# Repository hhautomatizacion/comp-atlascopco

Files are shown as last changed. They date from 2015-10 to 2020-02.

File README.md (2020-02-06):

<br/>
<p align="center">
  
</p>
<br/>

# Control de compresor Atlas Copco

## Fecha
* 2014

## Descripcion del proyecto
* Reemplazo de control electronikon

## Herramientas utilizadas
* KGL_WIN version 3.66
* DopSoft version 1.01.08

## Modelos de PLC, etc.
* PLC MasterK 120s
* HMI Delta DOP-B05S111

## Autores
* <a href="http://www.github.com/emmanuel156">emmanuel156</a> 
* <a href="http://www.github.com/pedrohermon">pedrohermon</a> 

## Comentarios
* Aparte de las funciones básicas de arrancar y parar el compresor, el programa lleva la cuenta de horas de servicio para programar los mantenimientos al compresor. También se puede programar la hora y día de la semana de arranque y paro automático del compresor así como tener un historial de eventos del mismo.

## Contenido
* Carpeta de Diagramas
	* Diagramas del proyecto
		* Diagramas electricos
		* Diagramas de bloques
		* Dibujos
* Carpeta de Documentos
	* Documentos pensados para el usuario final
		* Manuales de usuario
		* Manuales de programacion
* Carpeta de Fotos
	* Fotos del proyecto antes, durante y despues del desarrollo del mismo
		* Fotos
		* Capturas de pantalla
* Carpeta de Historial
	* Documentacion del desarrollo del proyecto
		* Hojas de datos de componentes
		* Manuales de usuario de componentes
		* Documentacion de funciones, herramientas
* Carpeta de Programas
	* Programas de Computadora, PLC, etc. 
		* Codigos fuente
		* Iconos e imagenes usados en los programas
		* Archivos de configuracion de los programas
		* Programas compilados
* Carpeta de Pruebas
	* Pruebas preliminares del proyecto
		* Programas incompletos, o secciones de programas
		* Modelos de componentes que se hayan probado

---
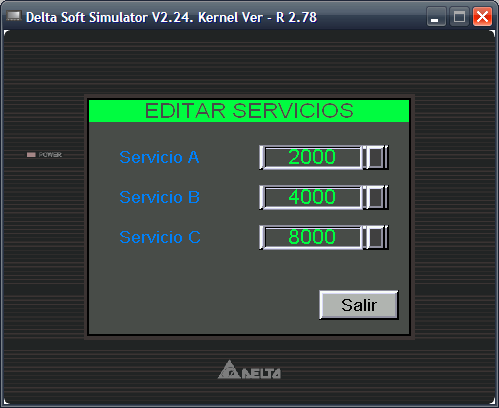
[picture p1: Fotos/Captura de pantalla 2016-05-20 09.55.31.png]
Captura de pantalla 2016-05-20 09.55.31.png

---
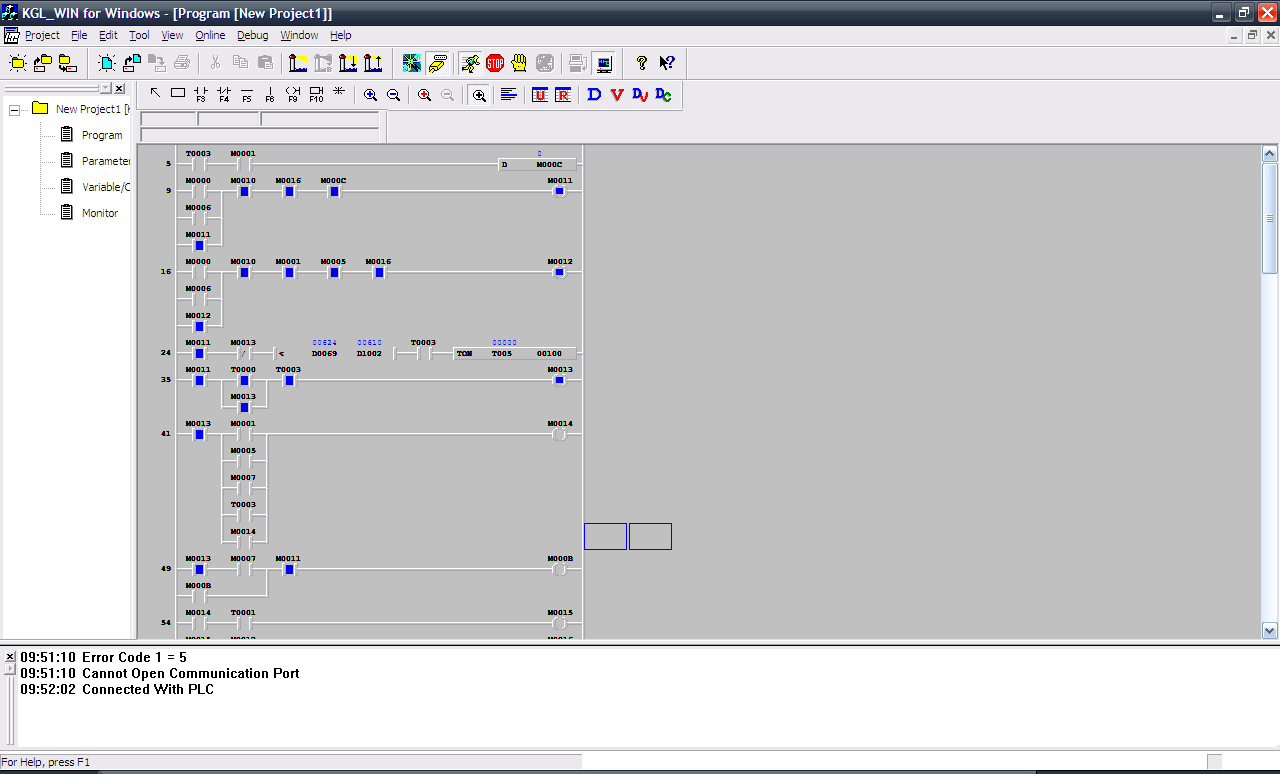
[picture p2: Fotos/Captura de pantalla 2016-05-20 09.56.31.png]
Captura de pantalla 2016-05-20 09.56.31.png

---
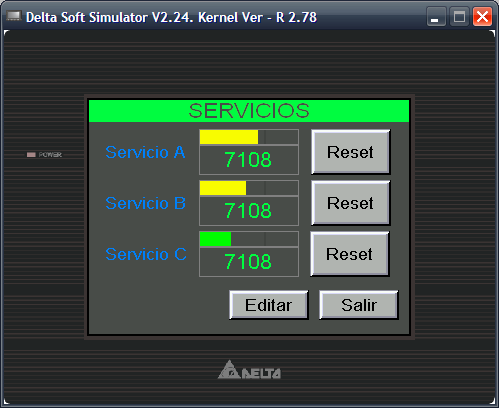
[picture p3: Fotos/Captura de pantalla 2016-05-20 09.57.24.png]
Captura de pantalla 2016-05-20 09.57.24.png

---
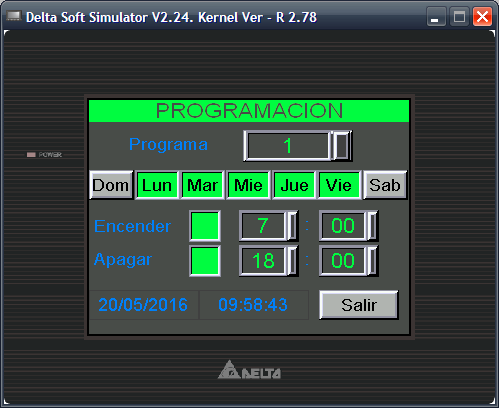
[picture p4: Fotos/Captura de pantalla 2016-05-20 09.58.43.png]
Captura de pantalla 2016-05-20 09.58.43.png

---
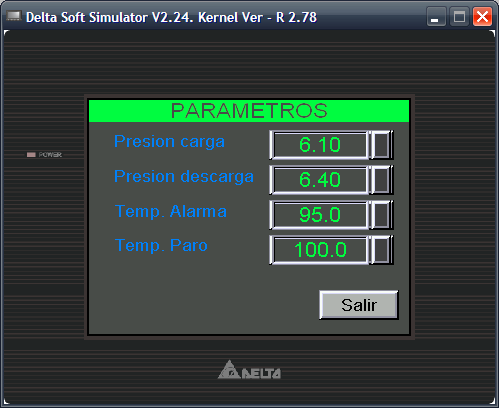
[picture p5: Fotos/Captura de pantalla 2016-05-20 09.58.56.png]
Captura de pantalla 2016-05-20 09.58.56.png

---
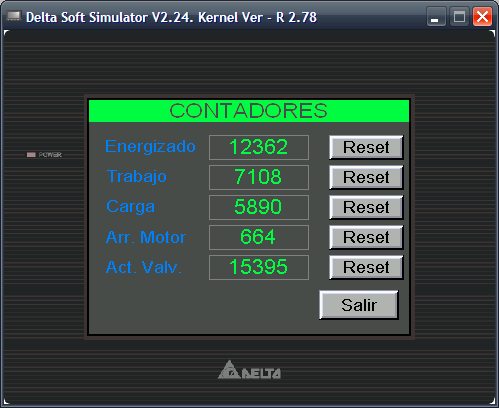
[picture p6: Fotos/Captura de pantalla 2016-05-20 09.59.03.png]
Captura de pantalla 2016-05-20 09.59.03.png

---
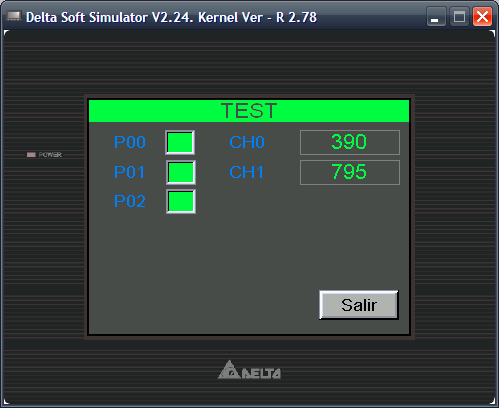
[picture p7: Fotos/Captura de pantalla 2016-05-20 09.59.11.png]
Captura de pantalla 2016-05-20 09.59.11.png

---
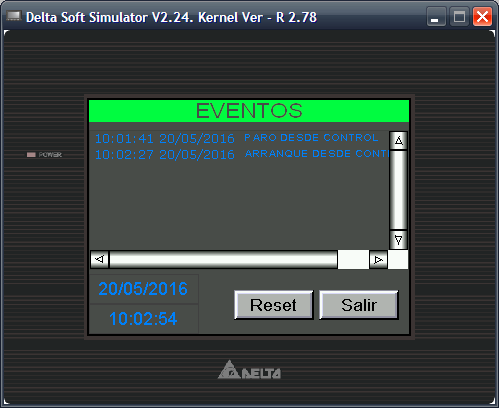
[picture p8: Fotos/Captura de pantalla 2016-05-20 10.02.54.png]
Captura de pantalla 2016-05-20 10.02.54.png

---
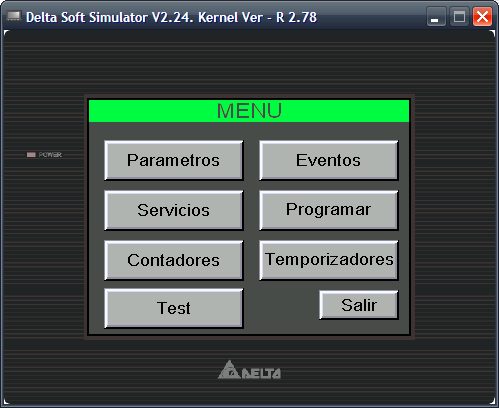
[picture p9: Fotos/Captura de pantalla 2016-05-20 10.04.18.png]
Captura de pantalla 2016-05-20 10.04.18.png

---
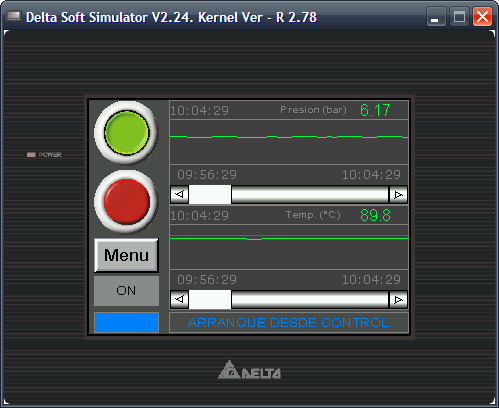
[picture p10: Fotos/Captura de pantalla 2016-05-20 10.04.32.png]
Captura de pantalla 2016-05-20 10.04.32.png

---
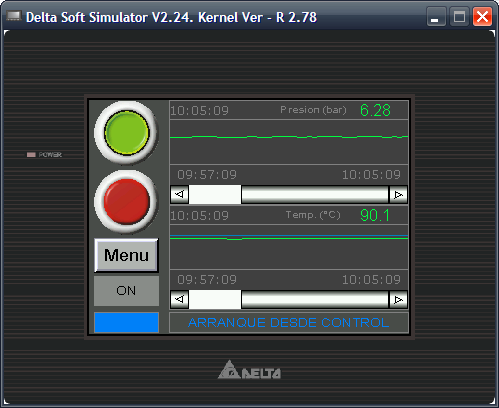
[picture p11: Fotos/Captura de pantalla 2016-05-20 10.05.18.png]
Captura de pantalla 2016-05-20 10.05.18.png

---
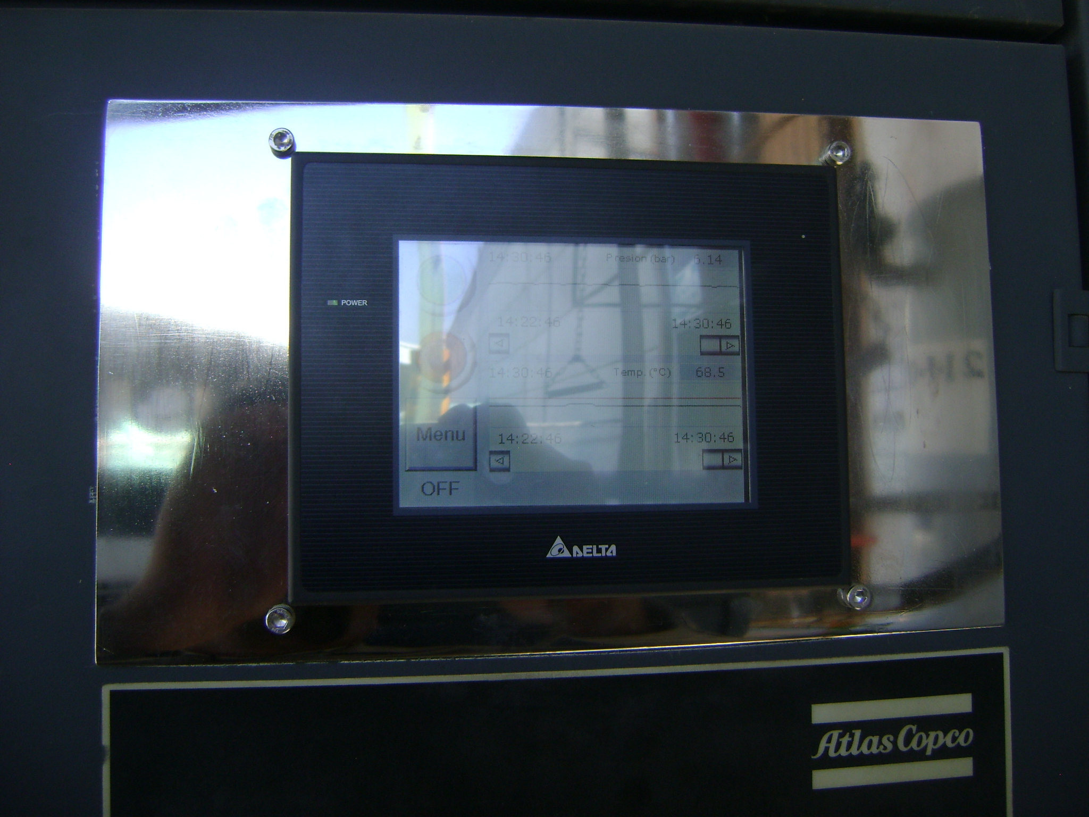
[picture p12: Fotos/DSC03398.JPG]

---
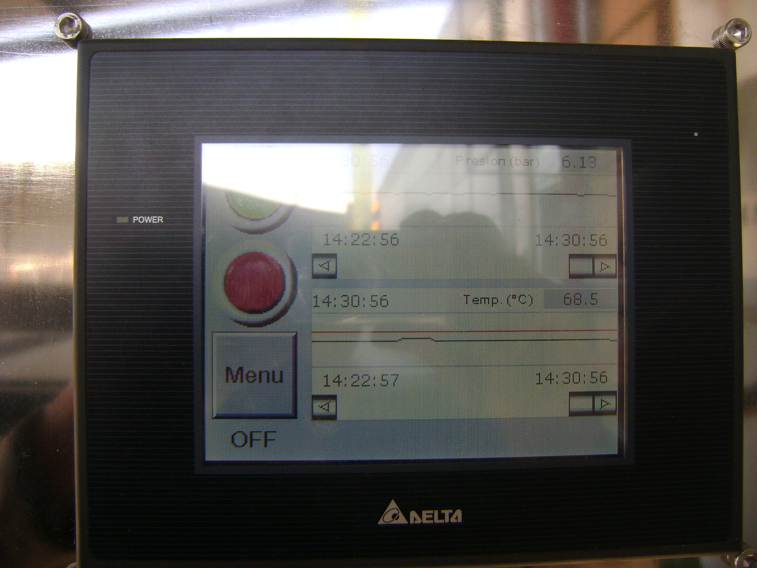
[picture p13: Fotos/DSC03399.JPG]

---
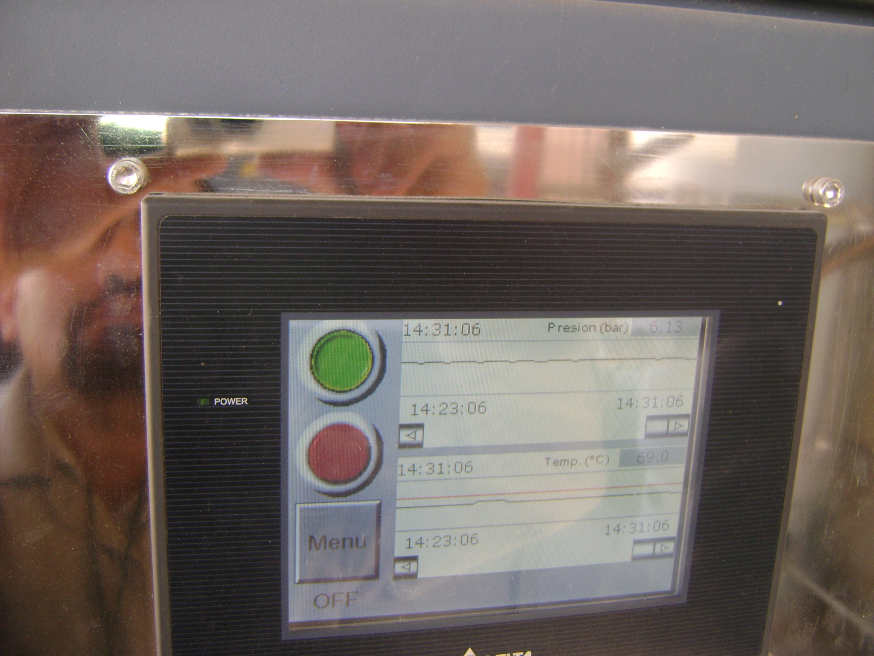
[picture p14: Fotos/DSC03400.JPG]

---
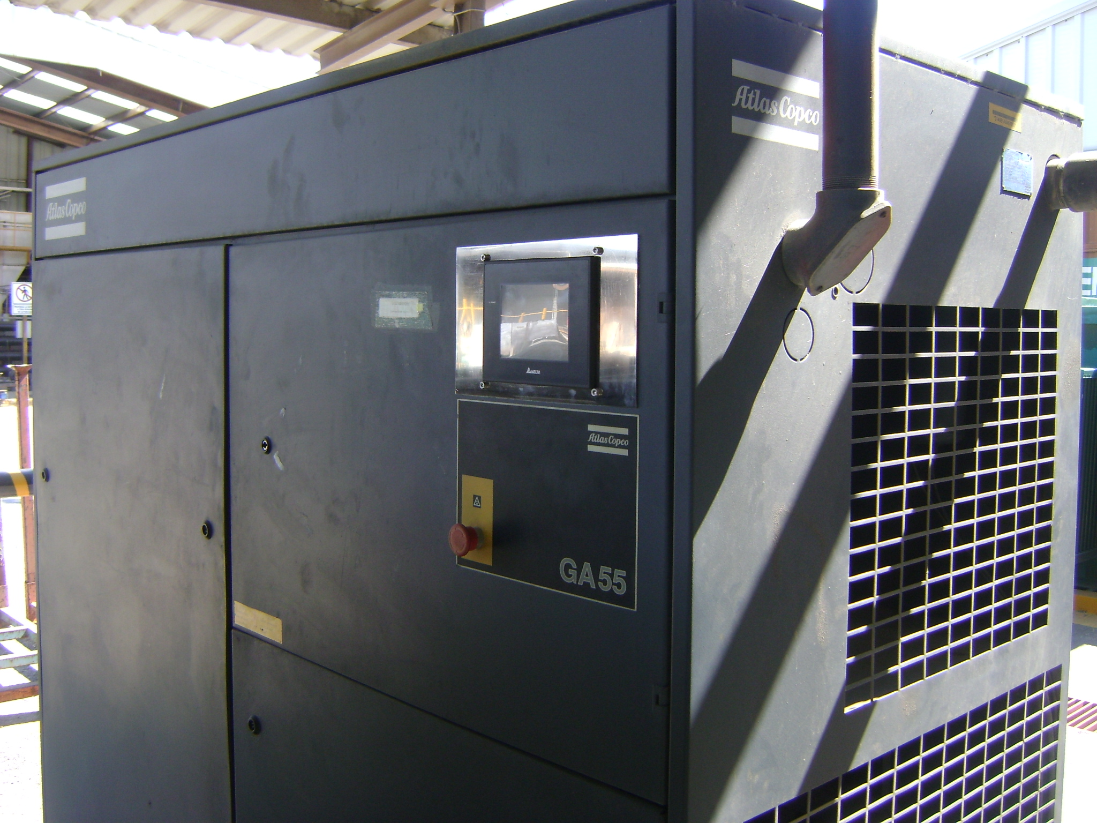
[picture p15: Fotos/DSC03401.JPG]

---
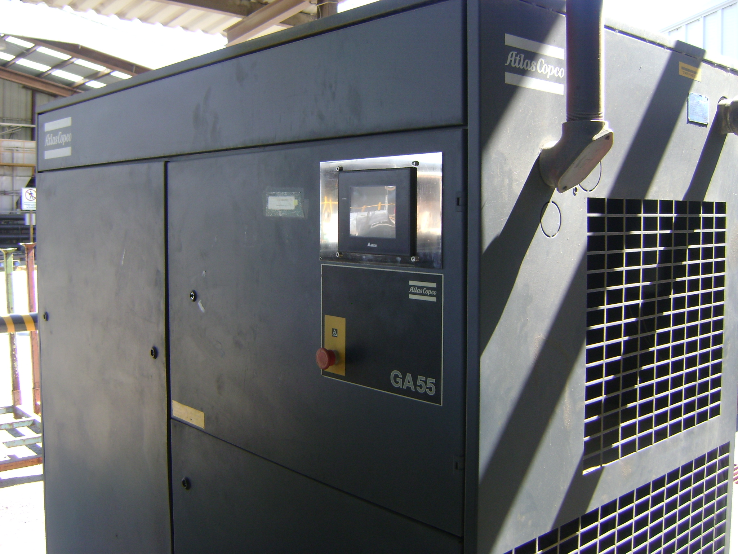
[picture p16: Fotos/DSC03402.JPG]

---
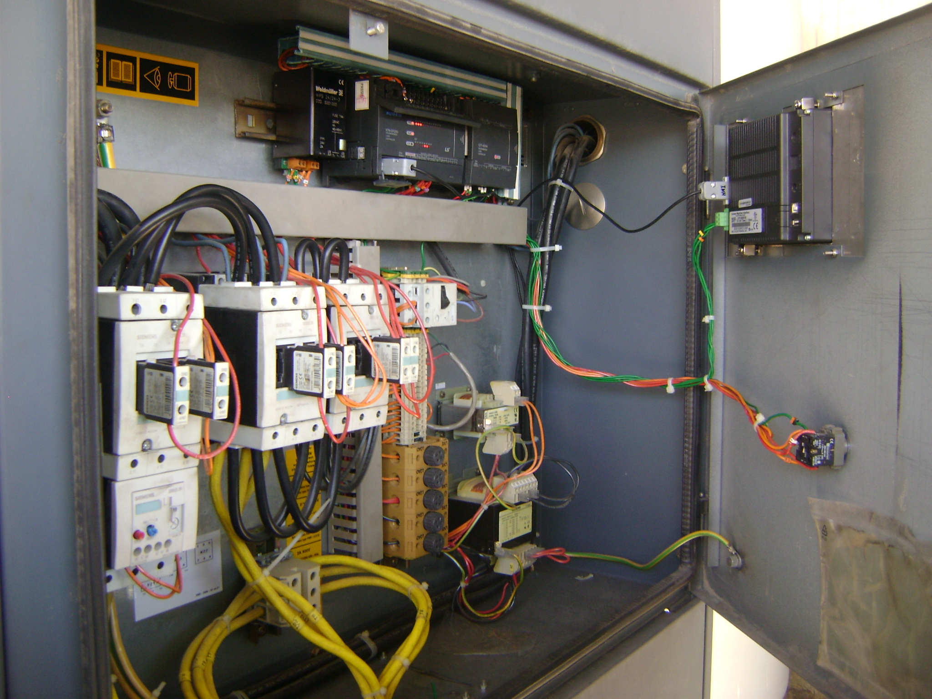
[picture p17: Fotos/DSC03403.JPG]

---
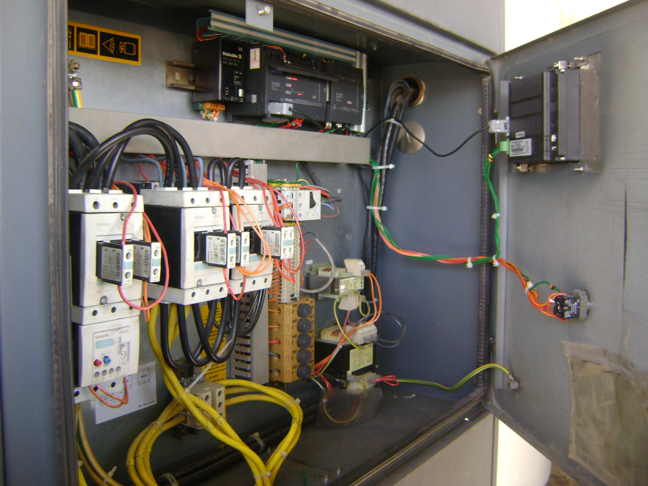
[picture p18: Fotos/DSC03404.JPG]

---
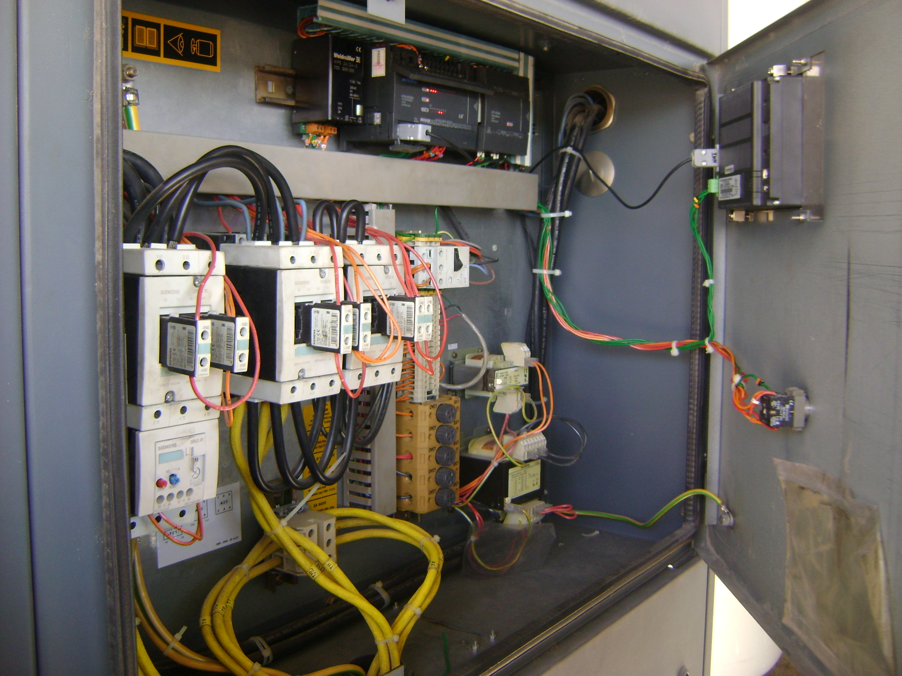
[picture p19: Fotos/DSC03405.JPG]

---
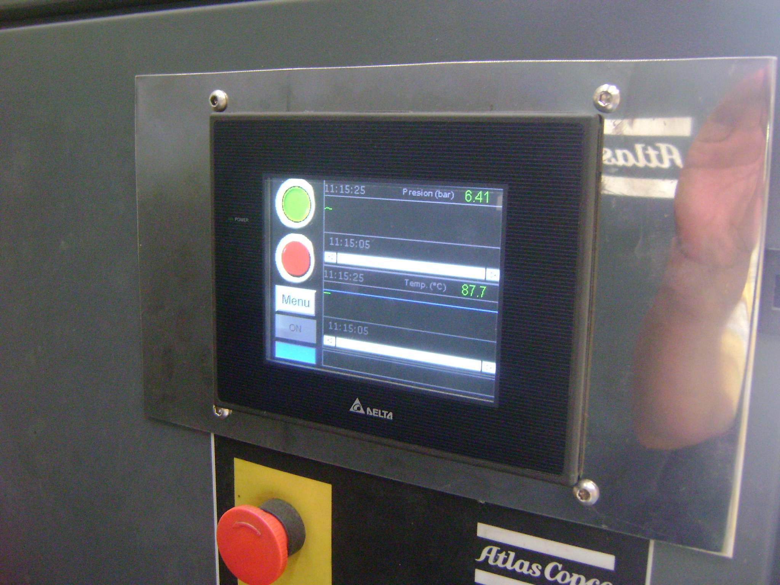
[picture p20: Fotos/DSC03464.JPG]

---
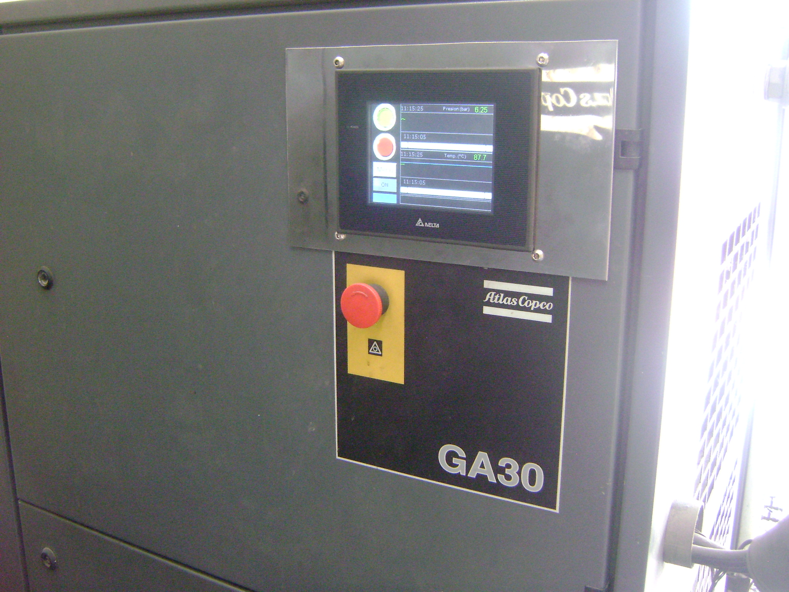
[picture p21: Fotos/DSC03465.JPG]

---
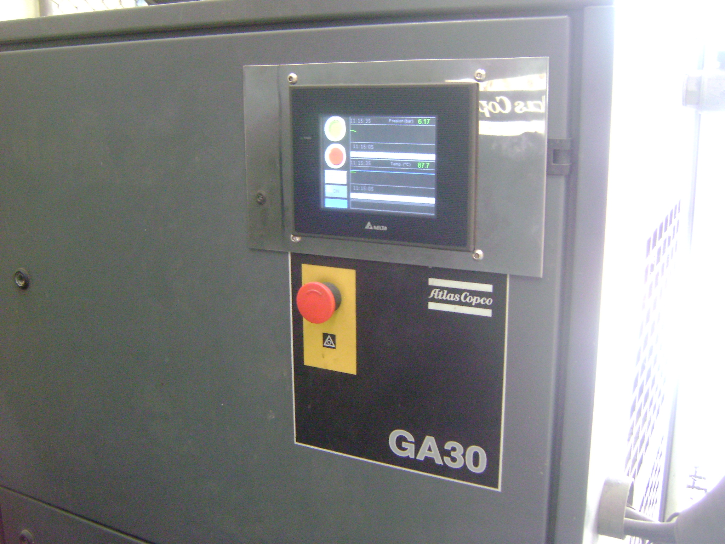
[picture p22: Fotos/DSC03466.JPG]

---
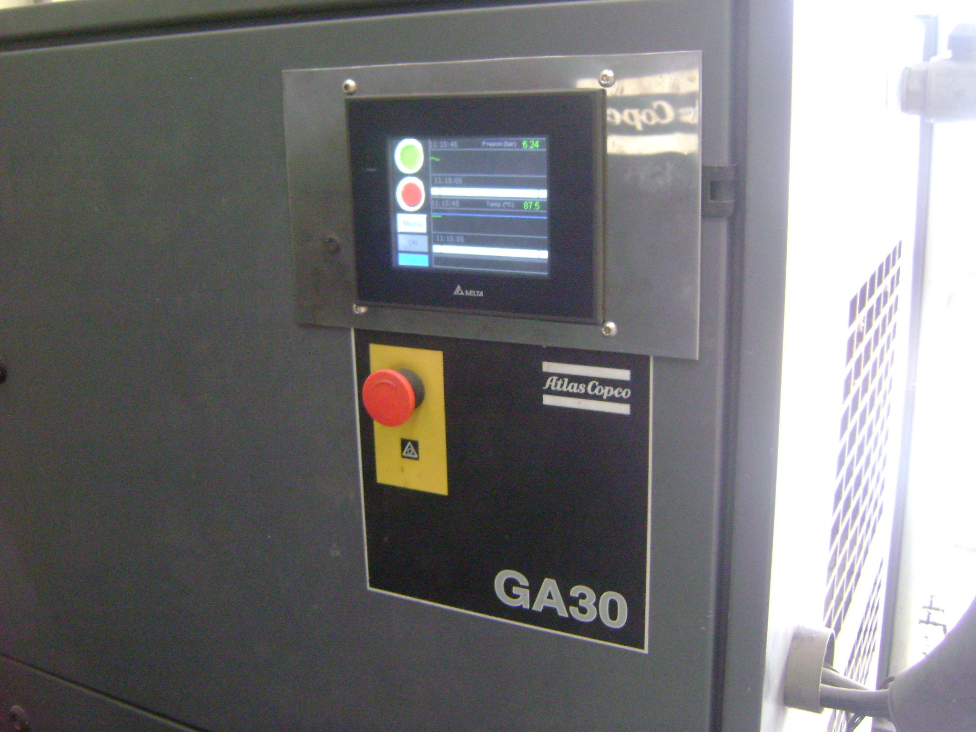
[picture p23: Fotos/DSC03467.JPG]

---
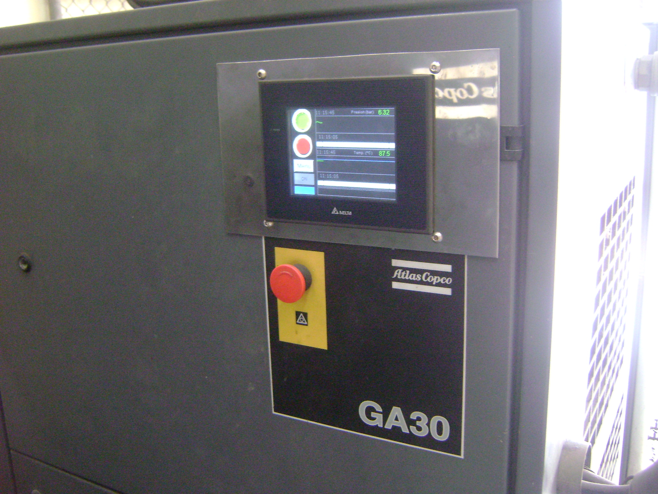
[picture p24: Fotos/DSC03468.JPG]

---
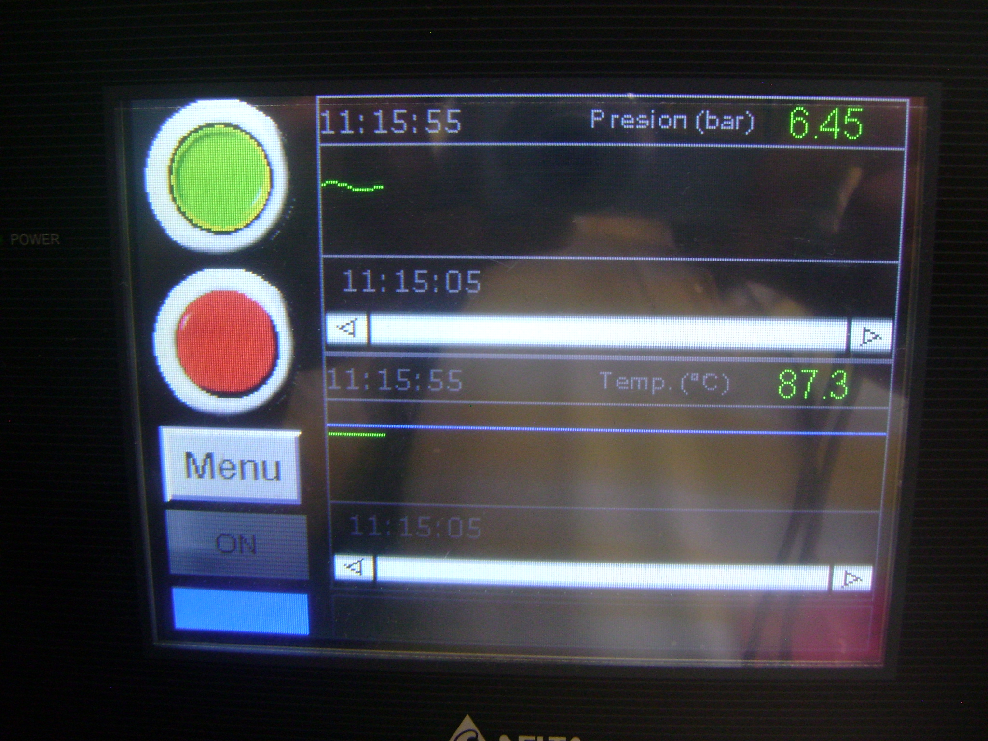
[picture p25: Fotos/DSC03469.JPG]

---
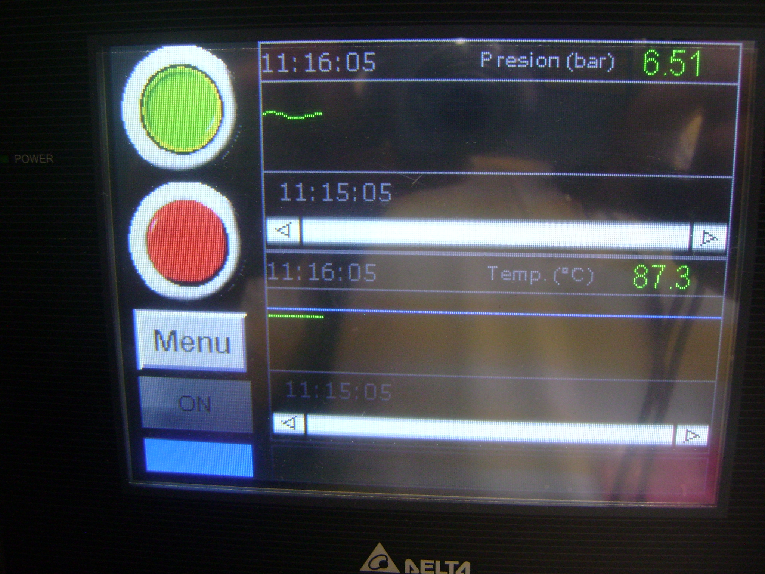
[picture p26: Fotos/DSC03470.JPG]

---
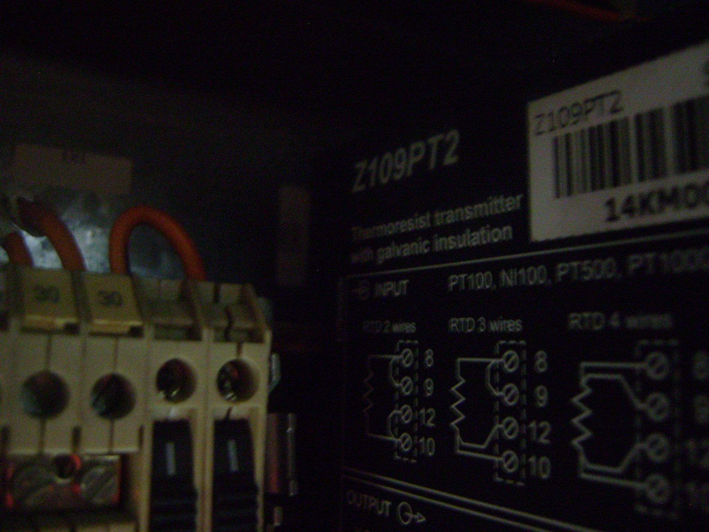
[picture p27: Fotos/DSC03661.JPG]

---
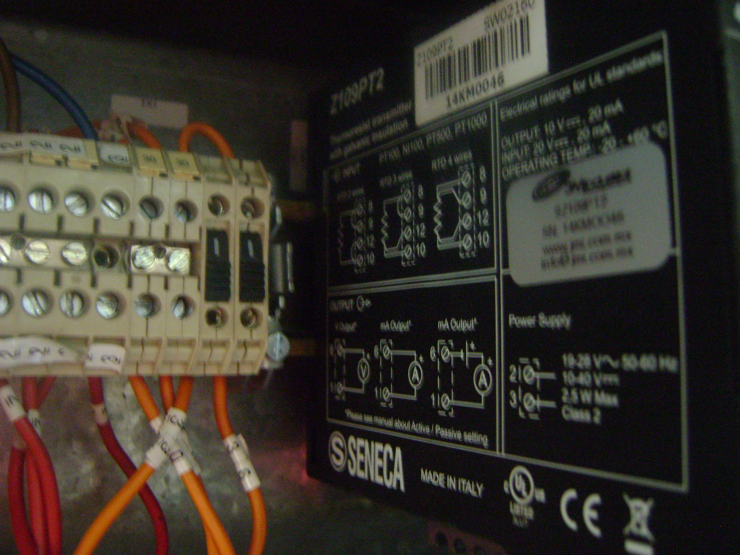
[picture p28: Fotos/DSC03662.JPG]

---
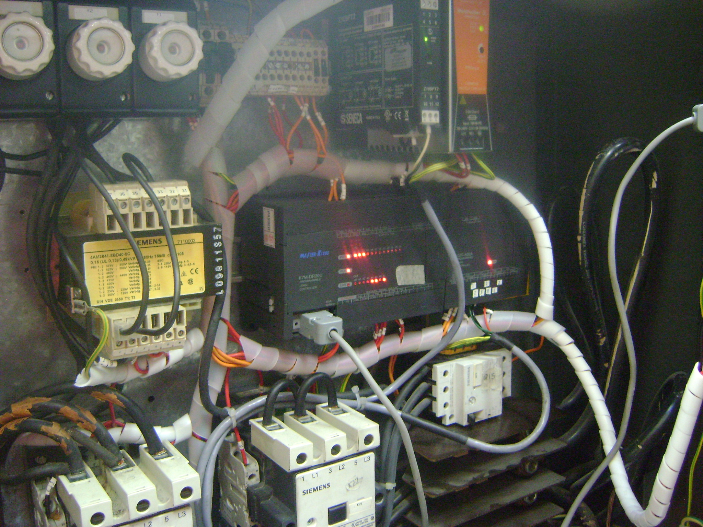
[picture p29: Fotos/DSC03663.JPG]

---
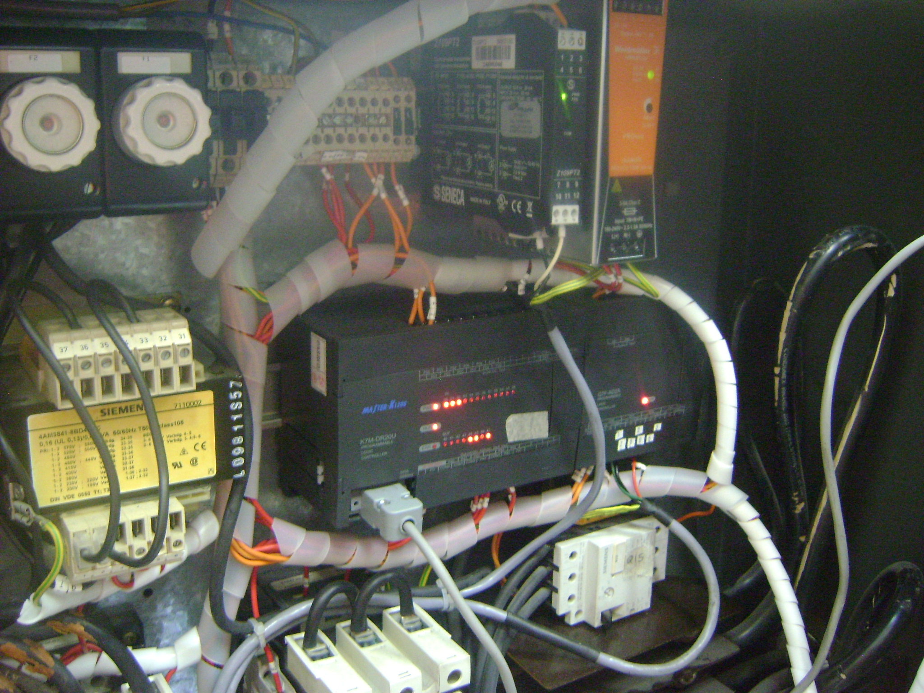
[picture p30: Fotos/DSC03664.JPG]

---
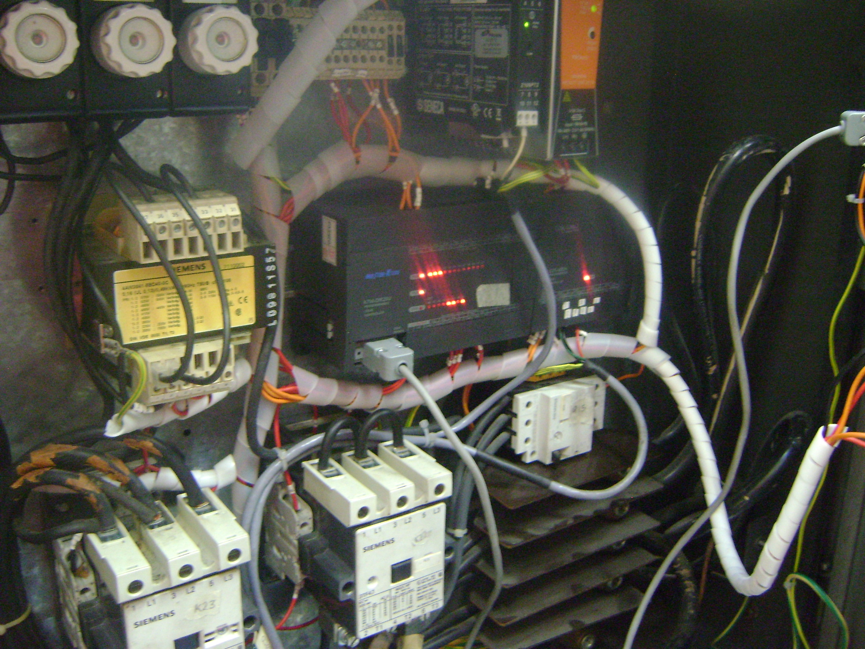
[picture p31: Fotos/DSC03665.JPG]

---
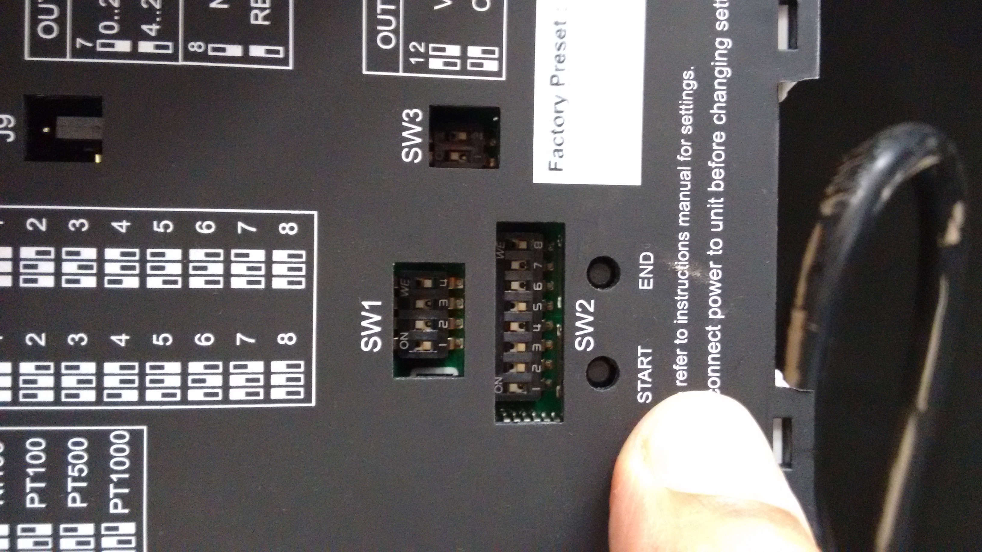
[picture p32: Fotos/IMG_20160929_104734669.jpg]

---
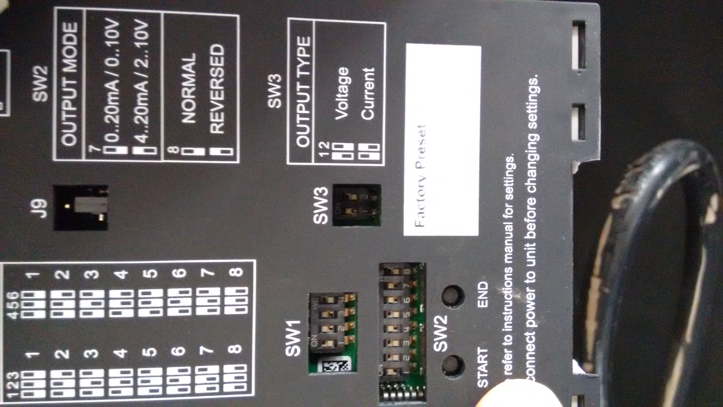
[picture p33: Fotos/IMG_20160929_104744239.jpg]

---
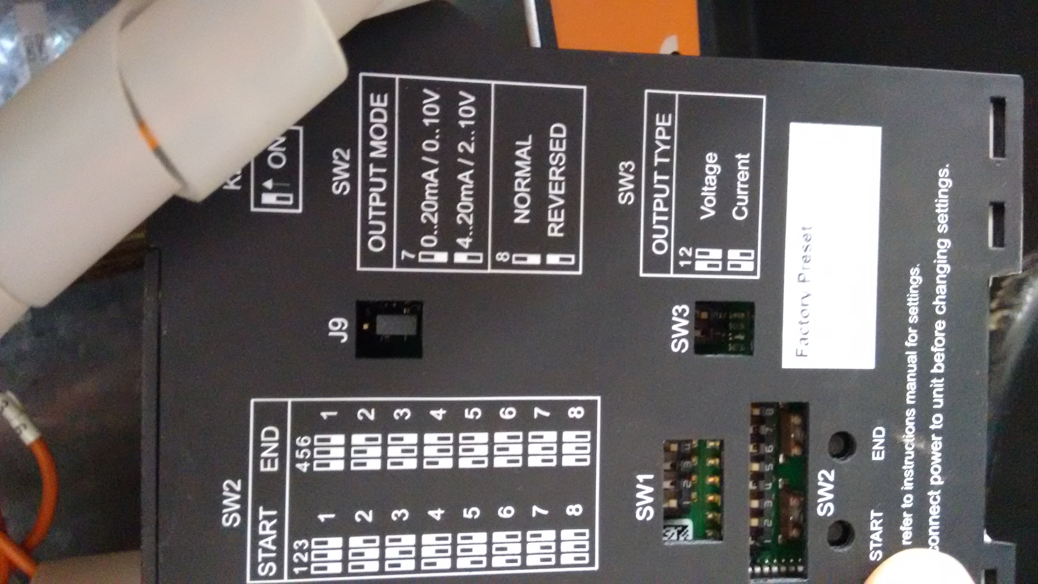
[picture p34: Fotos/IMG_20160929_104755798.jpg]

---
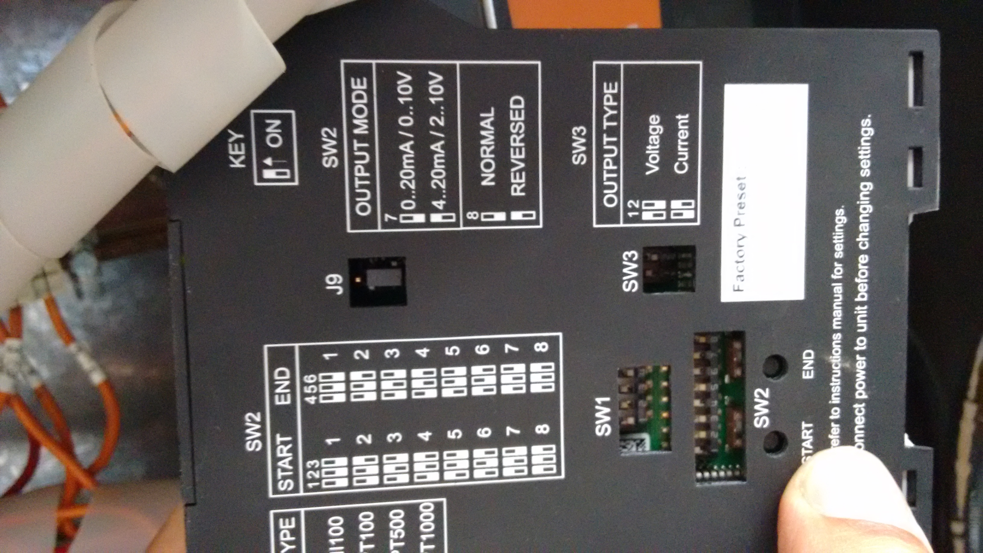
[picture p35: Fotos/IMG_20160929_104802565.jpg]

---
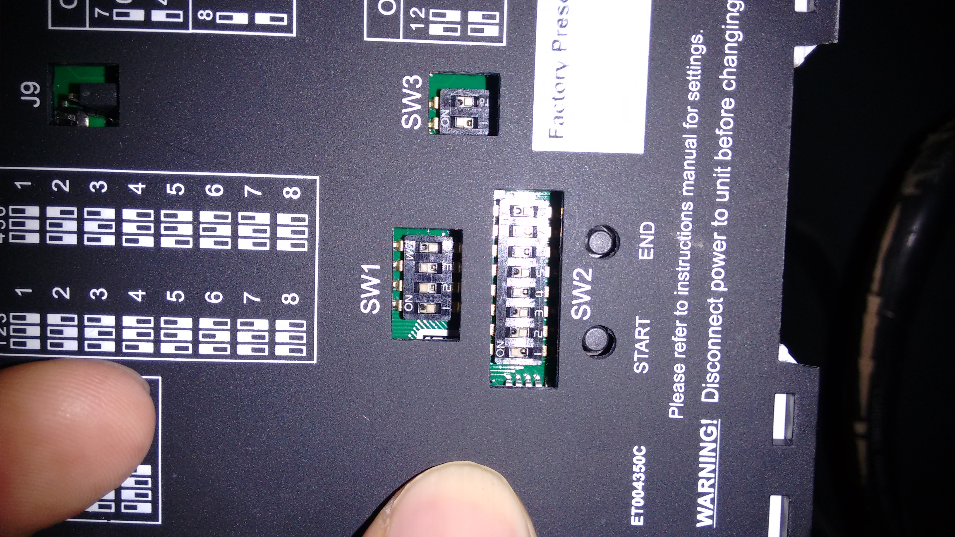
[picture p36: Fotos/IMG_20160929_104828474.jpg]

---
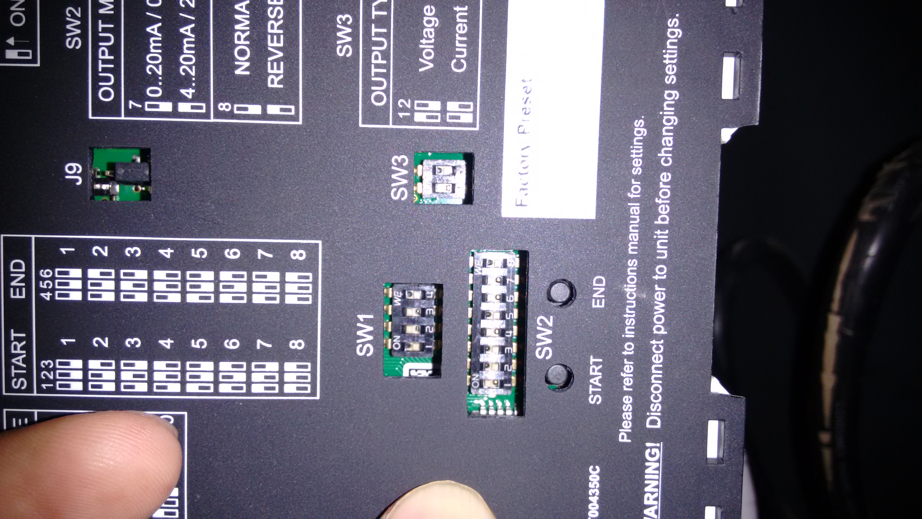
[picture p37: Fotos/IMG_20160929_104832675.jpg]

---
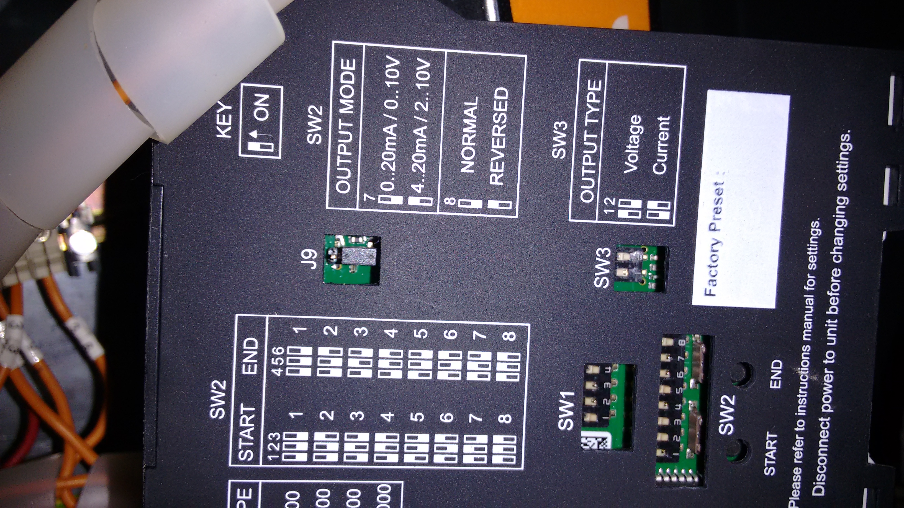
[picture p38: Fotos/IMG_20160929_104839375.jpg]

---
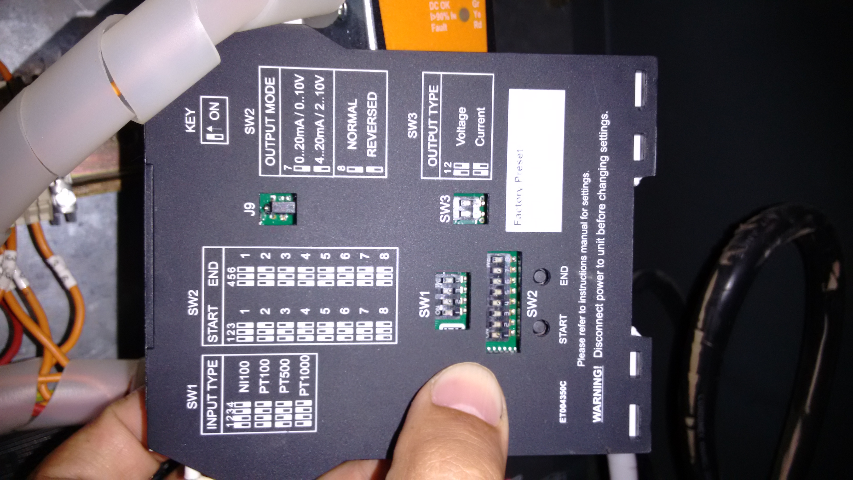
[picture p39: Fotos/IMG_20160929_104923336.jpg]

---
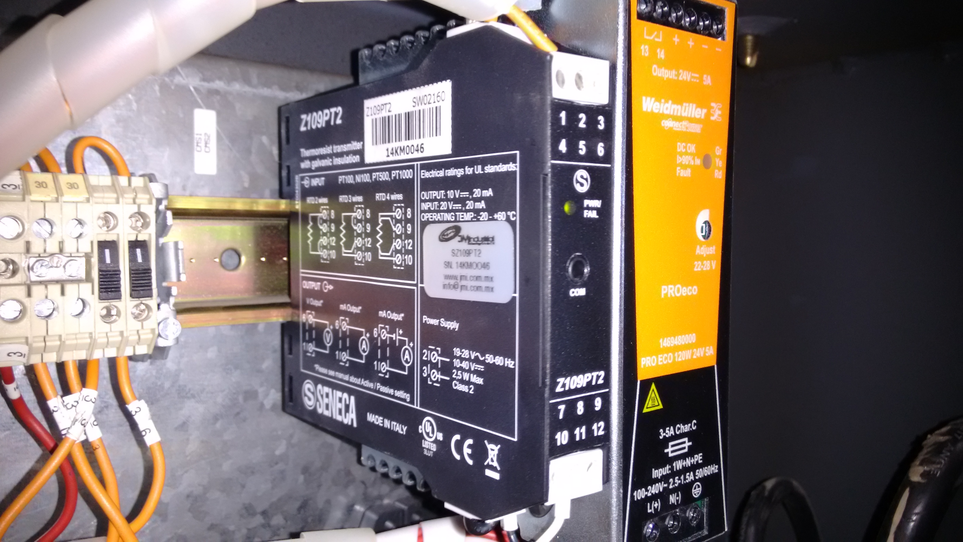
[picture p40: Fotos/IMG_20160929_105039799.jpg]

---

---

---

---

---

---

---

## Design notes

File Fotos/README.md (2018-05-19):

<br/>
<p align="center">
  
</p>
<br/>

# Carpeta de Fotos

## Fotos del proyecto antes, durante y despues del desarrollo del mismo

* Fotos

* Capturas de pantalla

---
Captura de pantalla 2016-05-20 09.55.31.png
---
Captura de pantalla 2016-05-20 09.56.31.png
---
Captura de pantalla 2016-05-20 09.57.24.png
---
Captura de pantalla 2016-05-20 09.58.43.png
---
Captura de pantalla 2016-05-20 09.58.56.png
---
Captura de pantalla 2016-05-20 09.59.03.png
---
Captura de pantalla 2016-05-20 09.59.11.png
---
Captura de pantalla 2016-05-20 10.02.54.png
---
Captura de pantalla 2016-05-20 10.04.18.png
---
Captura de pantalla 2016-05-20 10.04.32.png
---
Captura de pantalla 2016-05-20 10.05.18.png
---

---

---

---

---

---

---

---

---

---

---

---

---

---

---

---

---

---

---

---

---

---

---

---

---

---

---

---

---

---
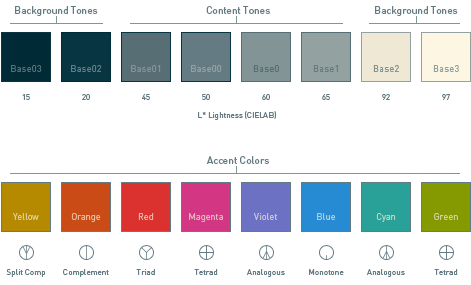
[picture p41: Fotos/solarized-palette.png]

---

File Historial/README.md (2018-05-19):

<br/>
<p align="center">
  
</p>
<br/>

# Carpeta de Historial

## Documentacion del desarrollo del proyecto

* Hojas de datos de componentes

* Manuales de usuario de componentes

* Documentacion de funciones, herramientas

---
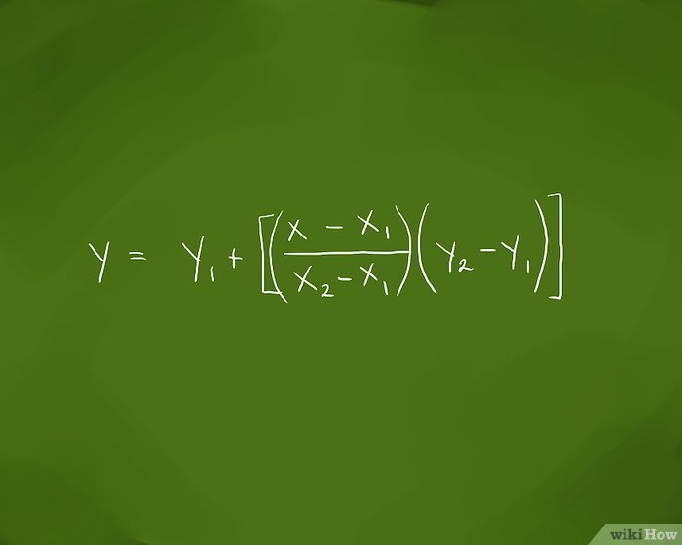
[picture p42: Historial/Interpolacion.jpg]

---
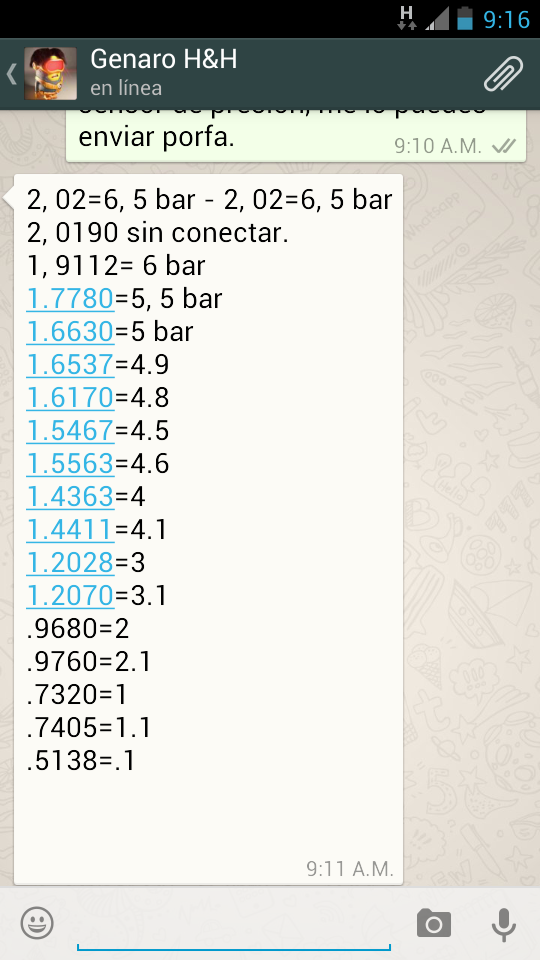
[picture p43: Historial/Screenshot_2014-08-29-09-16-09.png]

---
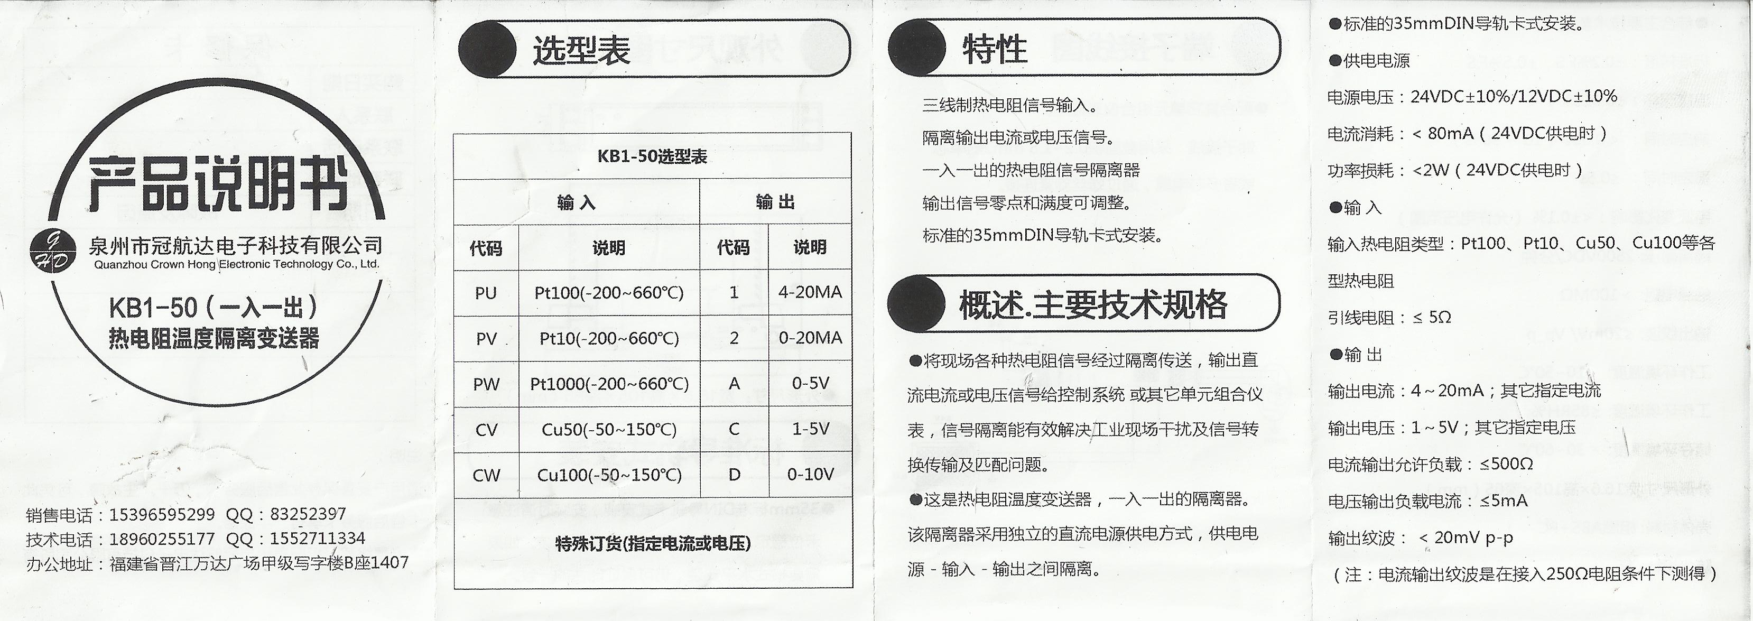
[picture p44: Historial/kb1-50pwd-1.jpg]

---
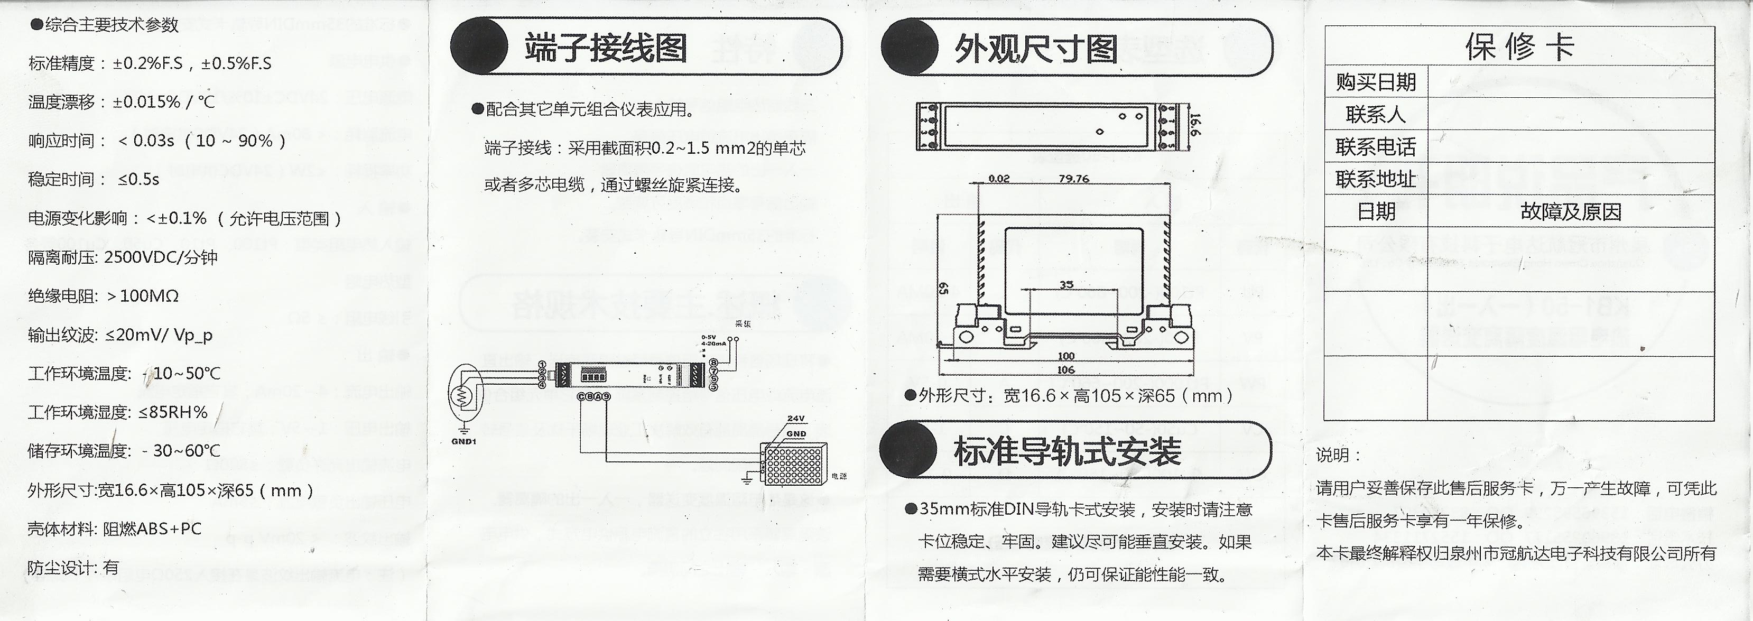
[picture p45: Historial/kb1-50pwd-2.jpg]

---

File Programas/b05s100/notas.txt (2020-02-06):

No editar!

Editar la version para dop-b05s111 y de ahi convertir.
Reducir la cantidad de "history buffer" para que no marque error de que no tiene suficiente SRAM

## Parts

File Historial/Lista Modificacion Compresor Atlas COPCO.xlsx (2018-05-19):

MATERIAL PARA ADAPTACION DE PLC, MARCA: LS A COMPRESOR ATLAS COPCO.
Cantidad | Unidad | DESCRIPCION
1 | pza | PLC Marca: LS Modelo: K7M-DR20U
1 | pza | Modulo de temperatura para PLC LS Modelo: G7F-AD2A
1 | pza | Pantalla HMI Marca: Delta Modelo: DOP-B05S111
1 | pza | Fuente de alimentacion marca: MEAN WELL, modelo: DR-120-24 ( ENTRADA: 120/220 VAC- SALIDA 24 VCD, 5 AMPERES )
1 | pza | Transmisor de temperatura de PT1000 a 0-5 VDC.
1 | pza | Platina de acero inoxidable, según modelo de compresor!
COMPLEMENTO
1 | pza | Interruptor Bifasico Merlin Gerin Multi9 C60N - C10 ( 10 amperes. )
1 | pza | Interruptor Bifasico Merlin Gerin Multi9 C60N - C6 ( 6 amperes. )
15 | pza | (clema) Borna de conexión por tornillo fijacion a riel DIN Calibre 12 color blanco
4 | pza | (clema) Borna de conexión por tornillo fijacion a riel DIN Calibre 12 color verde/amarillo (puesta a tierra)
4 | pza | Portafusible para riel DIN, para fusible tipo europeo.
4 | pza | Fusible tipo europeo de 3 Amps.
1 | pza | boton tipo hongo rojo, marca siemens completo. ( con 2 block de contactos NC )
4 | pza | relevador con bobina a 24 VDC, 1 contacto NO a 10 amperes, con base para riel DIN.
50 | mts | Cable de un polo color negro calibre 18
6 | pzas | Tornillos 5/32" x 1/2" inoxidable. ( completo )
30 | pzas | Tornillos 5/32" x 1/2" galvanizado. ( completo )
1 | mts | Riel din.
30 | pza | Cintilla plastica 10 cmts
30 | pza | Cintilla plastica 10 cmts
1 | pza | Conectro BD9 Hembra
1 | pza | Conectro BD9 Macho
2 | pza | Concha para Conector DB9
Transmisor de temperatura de PT1000 a 0-5 VDC.
https://es.aliexpress.com/item/Signal-Isolation-Transmitter-RTD-Input-0-10V-4-20mA-DC-output-Analog-Convertion-Module-DIN-Rail/937050768.html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
 |  | 2016-05-01
Notas:
.--Esta lista contempla material, solo para reemplazo de electronikon!
.--No para reemplazo de sensor temperatura y cable, transductores de presion y cables, contactores, cables de potencia, etc.
.--Checar lo del transmisor de temperatura, para tenerlo, cuando se requiera!

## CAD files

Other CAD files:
Diagramas/Modificacion COMPRESOR ATLAS GA15.dwg

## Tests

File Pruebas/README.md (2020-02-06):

<br/>
<p align="center">
  
</p>
<br/>

# Carpeta de Pruebas

## Pruebas preliminares del proyecto

* Programas incompletos, o secciones de programas

* Modelos de componentes que se hayan probado

---
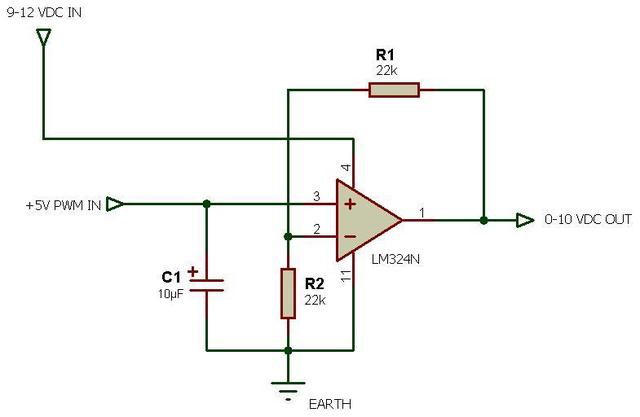
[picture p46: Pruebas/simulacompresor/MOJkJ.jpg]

---

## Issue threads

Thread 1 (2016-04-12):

No muestra pantalla de alarmas

mantenimientocl, 2016-04-12:
Se encontro que el programa no muestra la pantalla de alarmas. El termico del compresor se habia botado sin embargo no mostraba ninguna pantalla de advertencia. Incluso en la pantalla test mostraba que todas las condiciones de operacion estaban bien.

Closed 2016-11-01.

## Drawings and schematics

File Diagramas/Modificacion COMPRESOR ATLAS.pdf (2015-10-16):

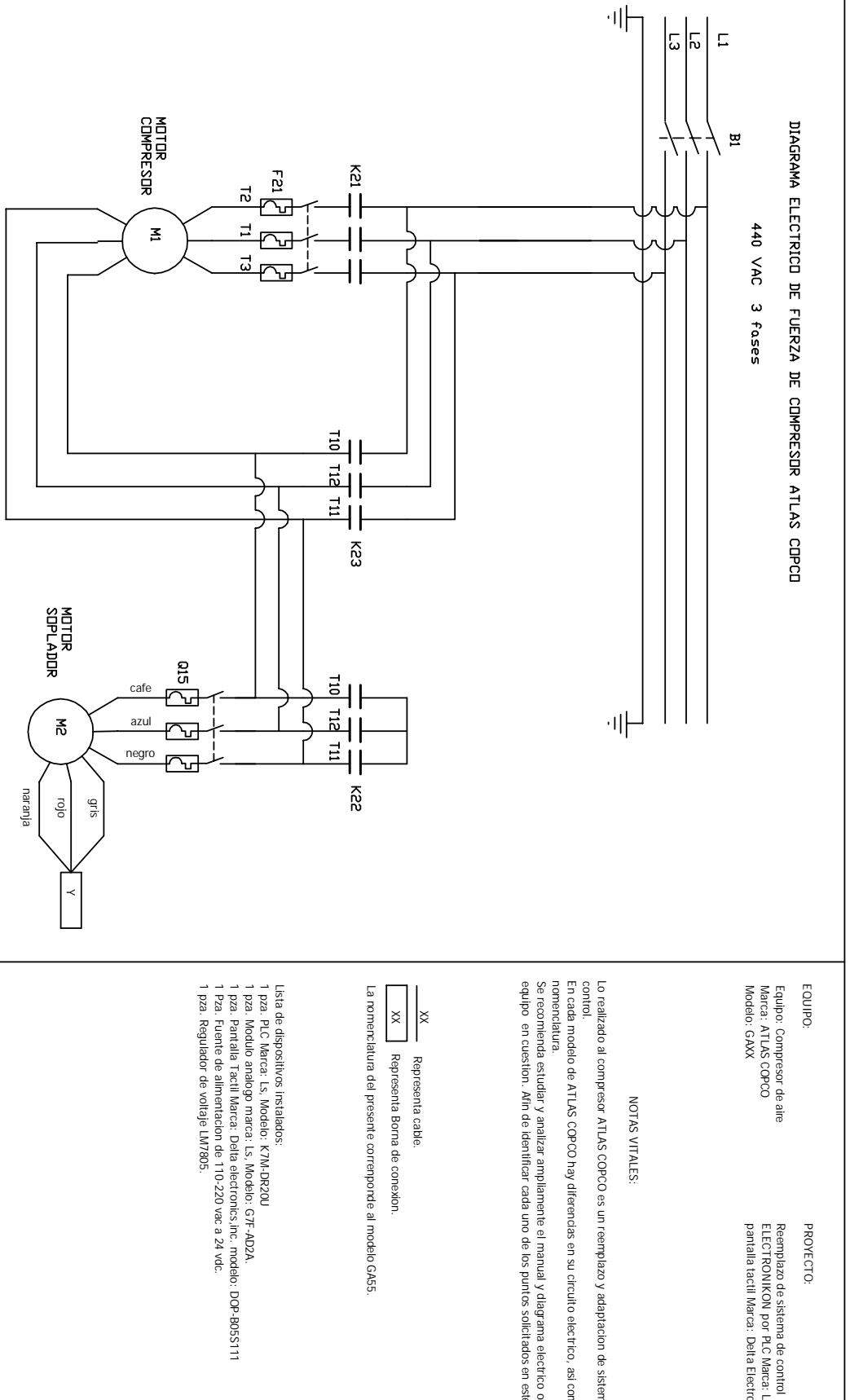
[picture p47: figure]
naranja; rojo; gris; cafe; azul; negro; Modelo: GAXX; Marca: ATLAS COPCO; Equipo: Compresor de aire; EQUIPO:; Representa Borna de conexion.; Representa cable.; 1 pza. Regulador de voltaje LM7805.; 1 pza. PLC Marca: Ls, Modelo: K7M-DR20U; Lista de dispositivos instalados:; NOTAS VITALES:; Reemplazo de sistema de control; PROYECTO:; nomenclatura.; control.

1 Pza. Fuente de alimentacion de 110-220 vac a 24 vdc.

1 pza. Pantalla Tactil Marca: Delta electronics,inc. modelo: DOP-B05S111

1 pza. Modulo analogo marca: Ls, Modelo: G7F-AD2A.

pantalla tactil Marca: Delta Electronics, inc.

ELECTRONIKON por PLC Marca: Ls y equipo en cuestion. Afin de identificar cada uno de los puntos solicitados en este apartado.

Se recomienda estudiar y analizar ampliamente el manual y diagrama electrico original del

En cada modelo de ATLAS COPCO hay diferencias en su circuito electrico, asi como en su

Lo realizado al compresor ATLAS COPCO es un reemplazo y adaptacion de sistema de

Por lo tanto se recomienda anexarlo al original, para futuras referencias.

El presente es un complemento de los manuales y diagramas electricos originales del equipo. La nomenclatura del presente correnponde al modelo GA55.

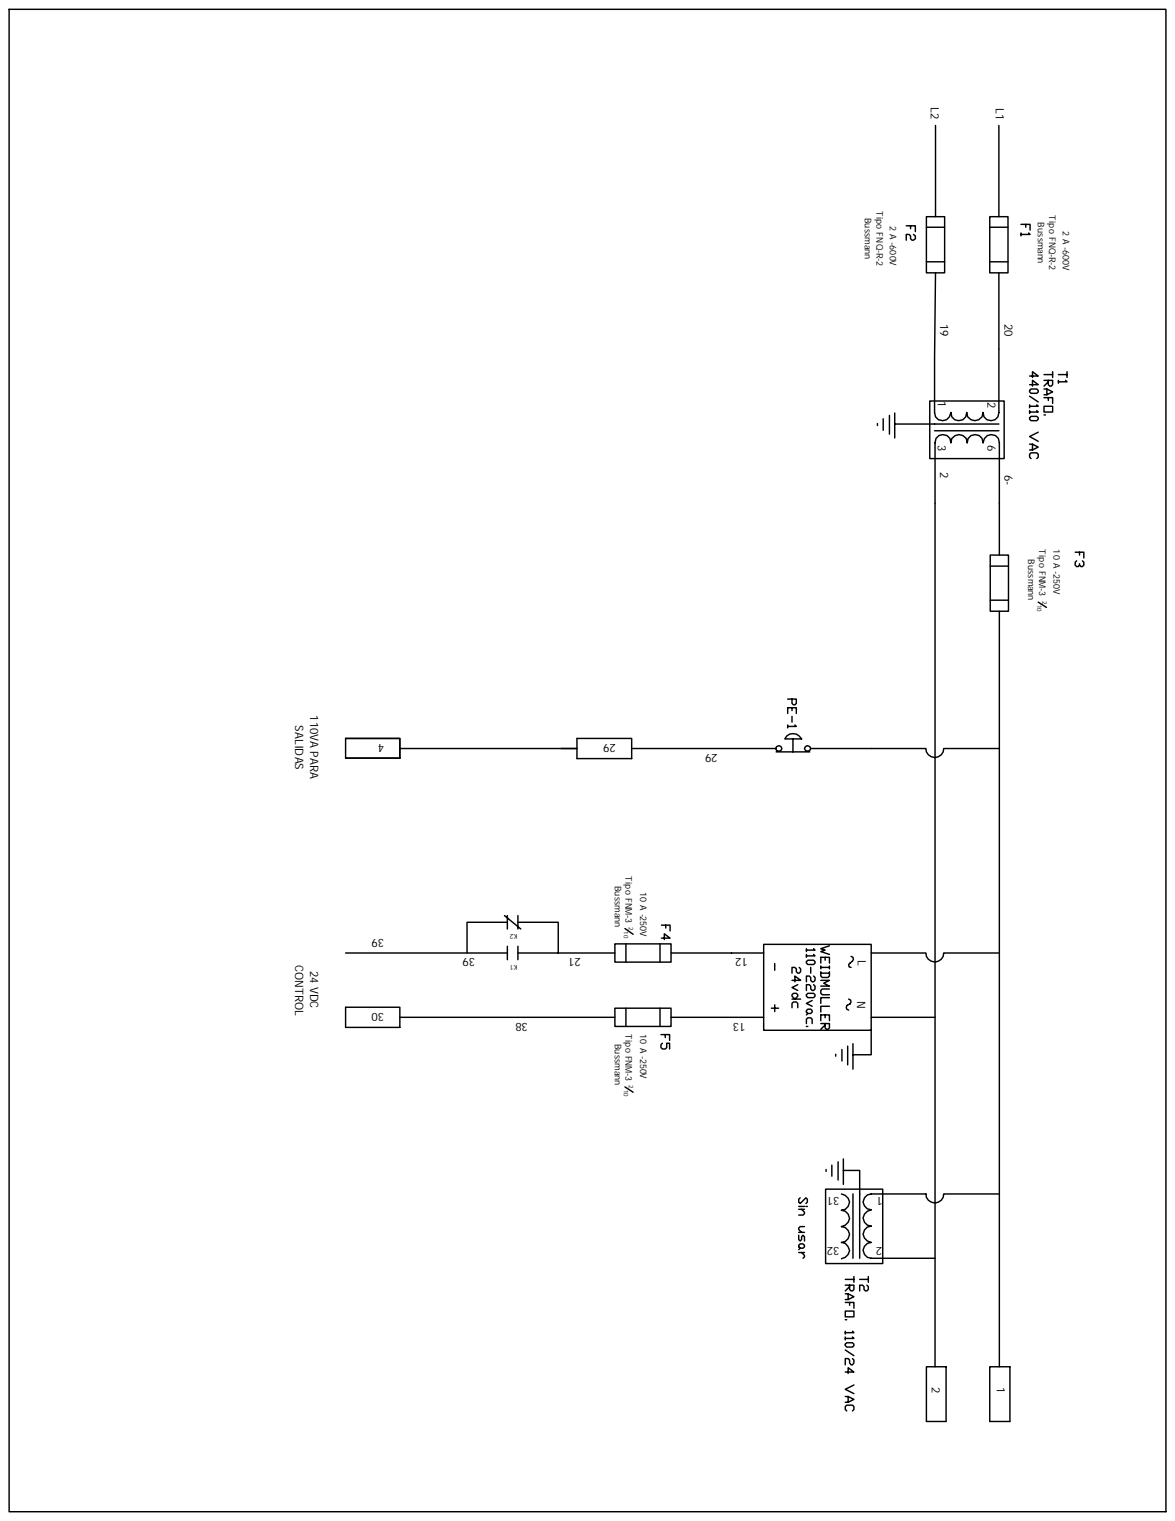
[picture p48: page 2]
Tipo FNM-3 2 10 Bussmann; Tipo FNQ-R-2; Bussmann; 110VA PARA; SALIDAS; 24 VDC; CONTROL

## ENTRADA DE EMERGENCIA

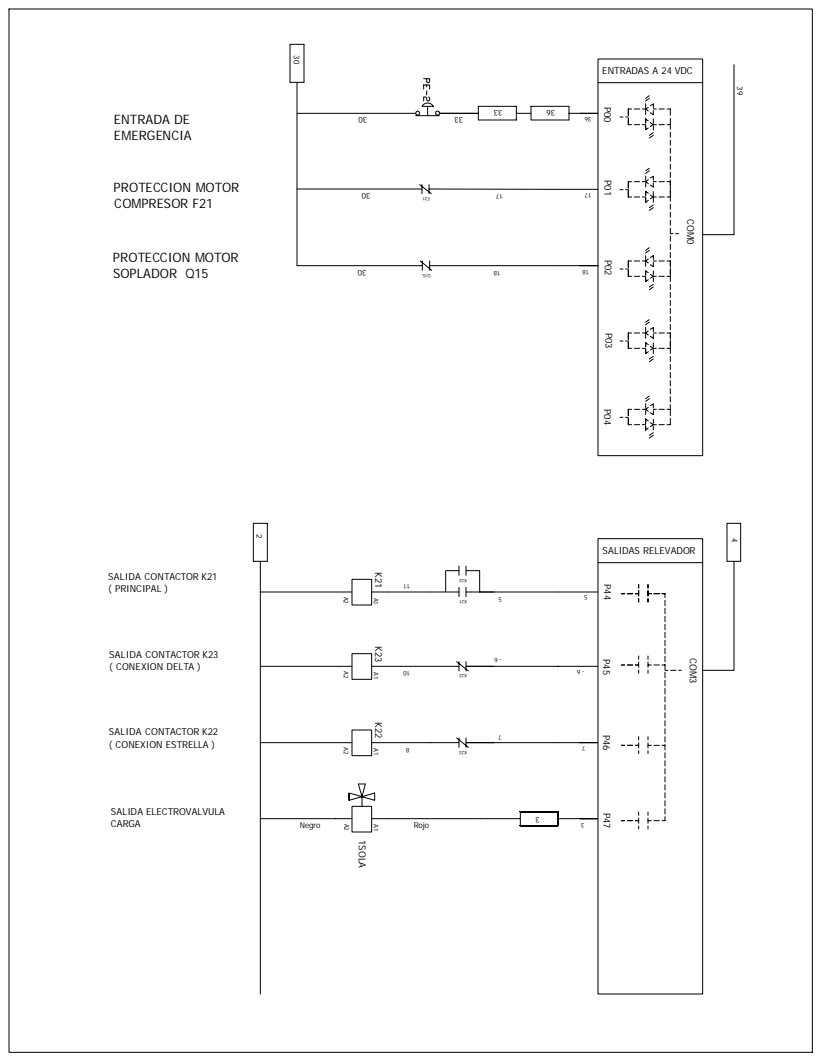
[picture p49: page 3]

### FG AC 100-240V

1
2

### 24V 24G . V+ V- I+ I-

COM0 V1 COM1 . V2 V0 COM2 MOD: G7F-AD2A MARCA: LS MODULO ANALOGO MOD: K7M-DR20U MARCA: LS PLC 24G 24V ENTRADA SALIDA RS485 +

Negro

TEMPERATURA DE
ELEMENTO

Negro

### MOD: DOP-B05S111 MARCA: DELTA

ELECTRONICS, INC.

## PANTALLA TACTIL +24V

0V 39

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
vdc positivos

Borna 30 de 24

ENTRADA TIERRA SALIDA

LM7805

39

30

sensores.

5 VDC Para

40

alimentar sensores de presion.

Instalar regulador de 5 VDC para

2 + 3 - 6 1
9 10 12 8

### MOD: SZ109PT2

### MARCA:

### CONVERTIDOR

Negro

Blanco

30

SENSOR RTD
( PT1000 )

50
52

Verde

verde

PRESION DE
SENSOR DE
LINEA

PRESION
SENSOR

DIFERENCIAL Desnudo Desnudo

Rojo

Rojo

40
39

39

Modelo: GAXX

Marca: ATLAS COPCO

Equipo: Compresor de aire

EQUIPO:

NOTAS:

pantalla tactil Marca: Delta Electronics, inc.

ELECTRONIKON por PLC Marca: Ls y

Reemplazo de sistema de control

PROYECTO:

armario electrico.

Se instala Plc con alimentacion de 110 a 220 vac, por tal razon se conecta a borna 1 y 2 de 1.- Salida para bobina de electrovalvula de carga

1.- Salida para bobina de contactor estrella (22)

1.- Salida para bobina de contactor delta (23)

1.- Salida para bobina de contactor principal (21)
Las salidas son a 110vac, y son las siguientes:
sensor, entrada solo aplica para compresores apartir de modelo GA55 en adelante)

3.- Entrada analoga diferencial ( de 0 a 5 VDC, el electronikon entrega 5VDC para alimentar

alimentar sensor )

2.- Entrada analoga de presion de salida ( de 0 a 5 VDC, el electronikon entrega 5VDC para

1.- Entrada analoga de temperatura de elemento ( RTD pt1000 )
El sistema cuenta con entradas analogas, y son las siguientes:
4.- 6 Entradas de electronikon (sin usar.)

3.- Entrada de proteccion de motor soplador (Q15)

2.- Entrada de proteccion de motor compresor (F21)

1.- Entrada de emergencia.
entradas que son las siguientes:

En el sistema original atlas copco la alimentacion de electronikon es a 24vac, asi tambien las

1.- Salida para bobina de electrovalvula de carga

1.- Salida para bobina de contactor estrella (22)

1.- Salida para bobina de contactor delta (23)

1.- Salida para bobina de contactor principal (21)
Salidas, Identificar las siguientes:

modelo GA55 en adelante)

3.- Entrada analoga diferencial ( de 0 a 5 VDC, solo aplica para compresores apartir de

2.- Entrada analoga de presion de salida ( de 0 a 5 VDC )

1.- Entrada analoga de temperatura de elemento ( RTD pt1000 )

Entradas analogas, Identificar las siguientes:
3.- Entrada de proteccion de motor soplador (Q15)

2.- Entrada de proteccion de motor compresor (F21)

1.- Entrada de emergencia.

Entradas, Identificar las siguientes:( GAXX )
en nagativo.

La salida negativa de la fuente se conecta al cable 39 del armario electrico, asi se convirtio
convirtio en positovo de 24 vdc.

La salida del positivo de la fuente se conecto a la borna 30 del armario electrico, asi se
Se reemplaza transformador de 110 a 24 vac por fuente de 110 vac a 24 vdc.
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

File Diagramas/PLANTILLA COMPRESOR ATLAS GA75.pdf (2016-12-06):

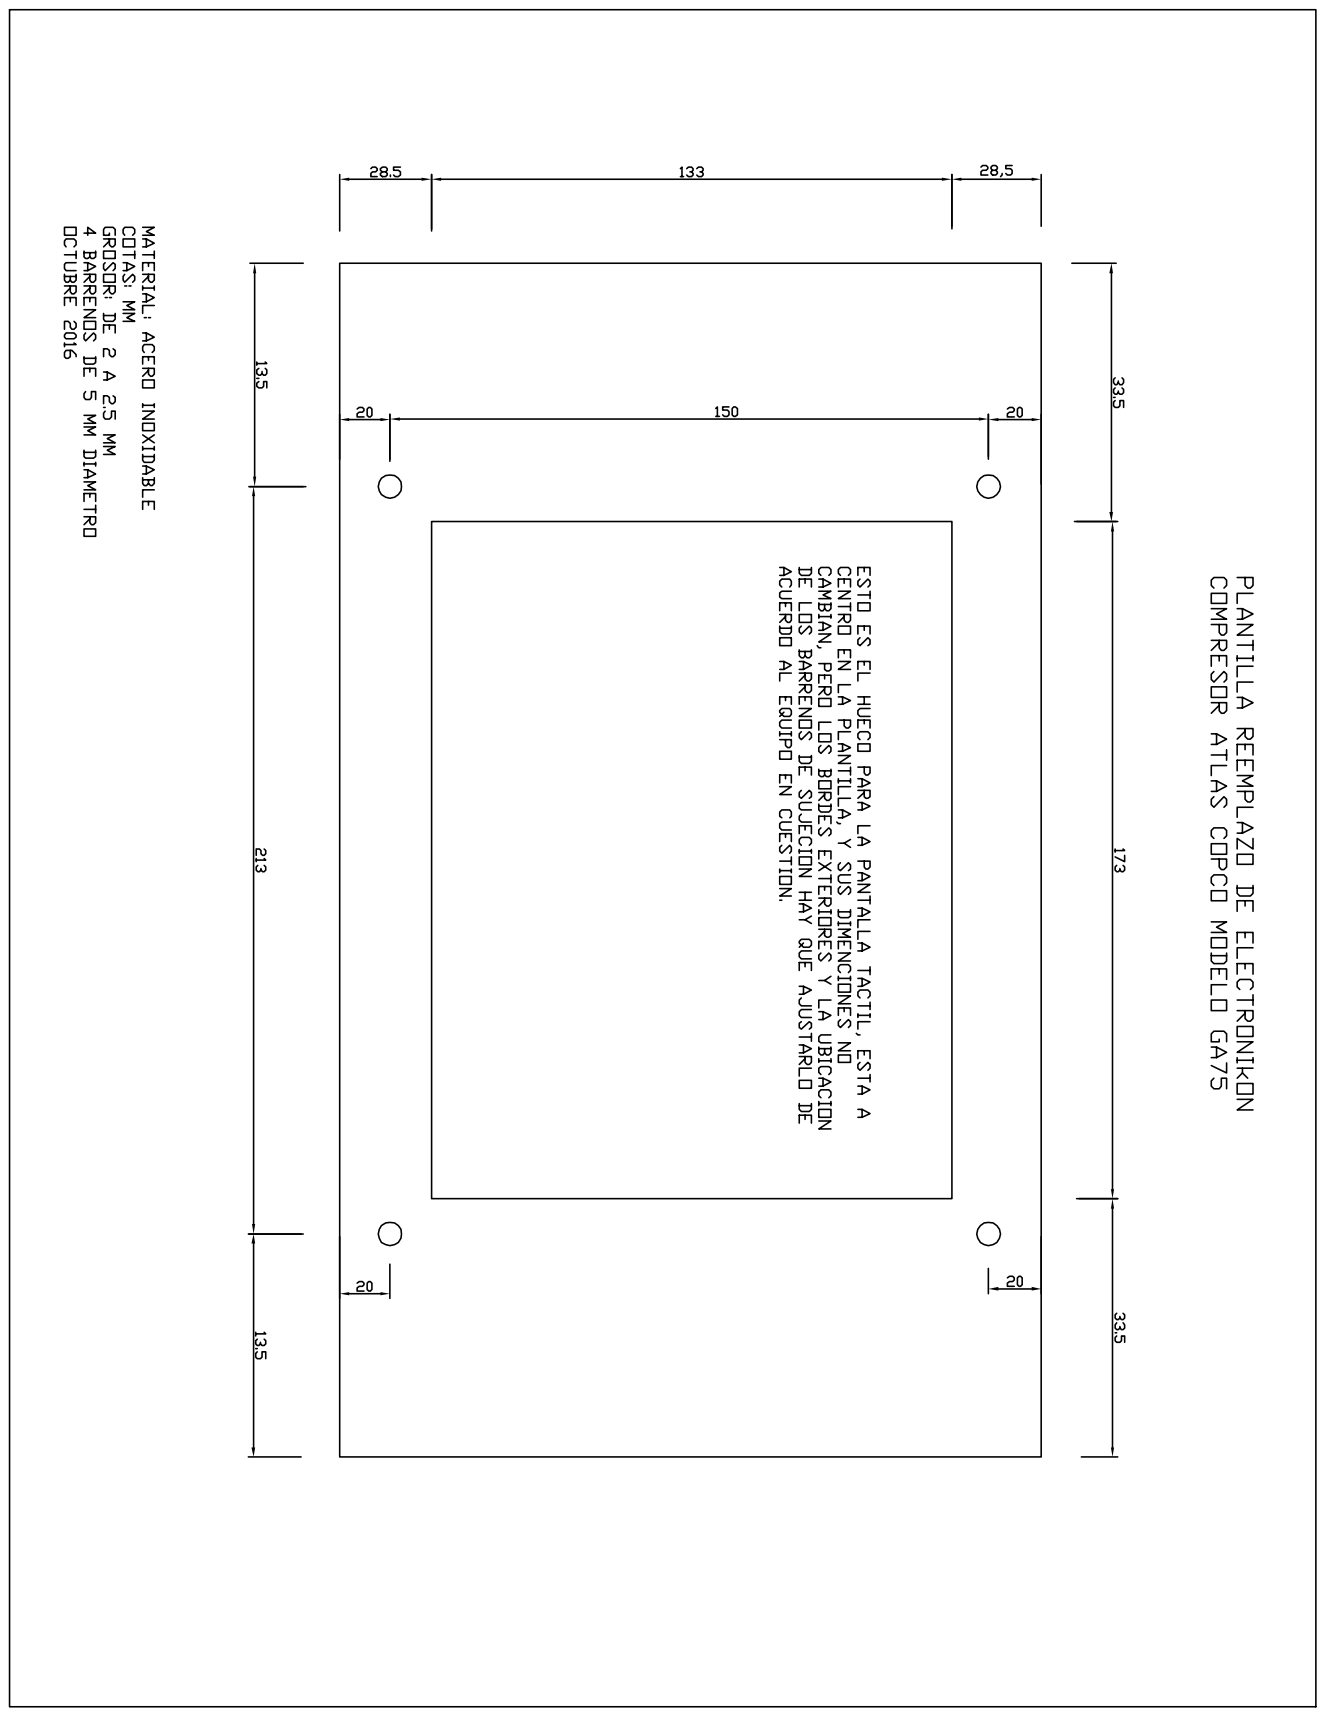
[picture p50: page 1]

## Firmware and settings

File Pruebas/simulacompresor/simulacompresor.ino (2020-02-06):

const int consumoInPin = A0;  // Analog input pin that the potentiometer is attached to
const int tempOutPin = 10; // Analog output pin that the LED is attached to
const int generacionInPin = A1;  // Analog input pin that the potentiometer is attached to
const int presionOutPin = 11; // Analog output pin that the LED is attached to

int sensorValue = 0;        // value read from the pot
float temperatura = 0;        // value output to the PWM (analog out)
float presion = 100;        // value output to the PWM (analog out)
float deltaPresion = 0;
int deltaTemp = 0;
int outPresion = 0;
int outTemp = 0;
int maxTemp = 25000;
int minTemp = 100;
int maxPresion =25000;
int consumo = 0;
int generacion = 0;

void setup() {
  pinMode(3,INPUT_PULLUP);
  pinMode(4,INPUT_PULLUP);
  Serial.begin(9600);
}

void loop() {
  // read the analog in value:
  delay(2);
  consumo = analogRead(consumoInPin);
  delay(2);
  generacion = analogRead(generacionInPin);
  
  deltaPresion = -(consumo / 100);
  if (digitalRead(3)==HIGH)  {
    presion = presion -5;
    maxTemp = 100;
    minTemp = 100;
    deltaTemp = 20;
  }
  if (digitalRead(3)==LOW)  {
    if (digitalRead(4)==LOW) {
      deltaPresion = ((generacion / 100) - (consumo / 100)); 
      maxTemp = 25000;
      minTemp = 24000;
      deltaTemp = 10;
    }
    else
    {
      deltaPresion = -((generacion / 100) - (consumo / 100)); 
      maxTemp = 22000;
      minTemp = 20000;
      deltaTemp = 5;
    }
  }

  presion = presion + deltaPresion;

  if (presion < 10) {
    presion = 10;
  }
  if (presion > maxPresion) {
    presion = maxPresion;
  }
  if (temperatura < minTemp) {
    temperatura = temperatura + deltaTemp;
  }
  if (temperatura > maxTemp) {
    temperatura = temperatura - deltaTemp;
  }
  
  outTemp = temperatura / 100;
  outPresion = presion /100;
  
  analogWrite(tempOutPin, outTemp);
  analogWrite(presionOutPin, outPresion);
  
  // print the results to the serial monitor:
  Serial.print("\n generado = " );
  Serial.print(generacion);
  Serial.print("\t consumo = " );
  Serial.print(consumo);

  Serial.print("\t temp = " );
  Serial.print(outTemp);

  Serial.print("\t delta = " );
  Serial.print(deltaPresion);
  
  Serial.print("\t presion = ");
  Serial.print(outPresion);

  delay(10);
}

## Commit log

2015-10-19 Se agrega previsualizacion de fotos.
2015-11-11 Se agregan fotos de adaptador de RTD a Voltaje.
2016-03-17 * Se corrige error no hacia caso a la programacion semanal.
2016-05-05 Se agrega manual de convertidor de rtd a voltaje.
2016-05-20 Se agregan capturas de pantalla
2016-10-17 Se agrega archivo de actualizacion de HMI
2016-10-24 * Se implementa #6. * Se agregan pantallas para configurar las entradas analogas. * Se cambia a pantalla modelo DOP-B05S111
2016-10-31 Se liberan versiones 1.00 de HMI y 1.00 de PLC.
2016-12-06 Lista de material para modificacion de compresor atlas copco.
    [Lista Modificacion Compresor Atlas COPCO.xlsx]
2017-03-08 Conexion analogo digital se agregan documentos.
    [CONVERSION TEMPERATURA.xlsx]
2018-05-16 Diagrama de compresor Atlas copco GA15 con modulo deshumificador Instalacion de CONTROL UNI-H&H, Modelo:
    [Modificacion COMPRESOR ATLAS GA15.dwg]
2018-05-19 Se agrega simulacompresor Se agrega pruebas de interpolacion
    [interpolacion.xlsx]
2020-02-06 Se separa version para b05s100 y b05s111
    [interpolacion.xlsx]
2020-02-06 Actualizacion de readmes
